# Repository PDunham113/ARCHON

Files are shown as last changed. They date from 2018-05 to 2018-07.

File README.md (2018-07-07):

# ARCHON
**A**ddressable **R**GB LED **CON**troller *(The **'h'** is nonexistent)*

The ultimate goal is to control an arbitrary number of addressable (WS2812 or
similar) from an ATMega328p, with a robust serial protocol to communicate to a
IoT-friendly mainboard (Raspberry Pi Zero W or similar).

Current state is somewhat less than that (setting up tools, etc.)

## Folders

### hardware (v0.0.0)
Contains EAGLE files for the ARCHON controller board

### software (v0.0.0)
Contains firmware for ARCHON

## Setup
Working with the hardware requires an installation of Autodesk EAGLE (v8.5.2 or
later), as well as a copy of Sparkfun's EAGLE library. Installation is left up
to the user.

Working with the software requires a number of (non-Windows-friendly) tools. To
automate the installation process and facilitate the ability to work on
multiple projects at once, a Vagrantfile is maintained with all the required
tools and dependencies.

### Installing Vagrant
You will need:
-   Vagrant [(HashiCorp)][vagrant_install]
-   VirtualBox [(Oracle)][virtualbox_install]
    -   Other VMs are available, but not actively supported by this project
-   VirtualBox Extensions [(Same place)][virtualbox_install]

The Vagrantfile used here is split into 3 parts.
-   `Vagrantfile`
    -   Deals with general configuration of VM instance
-   `Vagrantfile.project`
    -   Deals with project-specific tools and dependencies
-   `Vagrantfile.local`
    -   Deals with user preferences and machine-specific settings. As this is
        user-specific, Git will ignore this. A template
        (`Vagrantfile.local.example`) is included. Rename and enjoy!

To boot the VM, navigate to the project folder and run the following commands:
```
vagrant up
vagrant ssh
```

#### Common Errors
-   Ensure that virtualization extensions are enabled (you may need to check
    your BIOS)

[vagrant_install]: https://www.vagrantup.com/downloads.html
[virtualbox_install]: https://www.virtualbox.org/wiki/Downloads

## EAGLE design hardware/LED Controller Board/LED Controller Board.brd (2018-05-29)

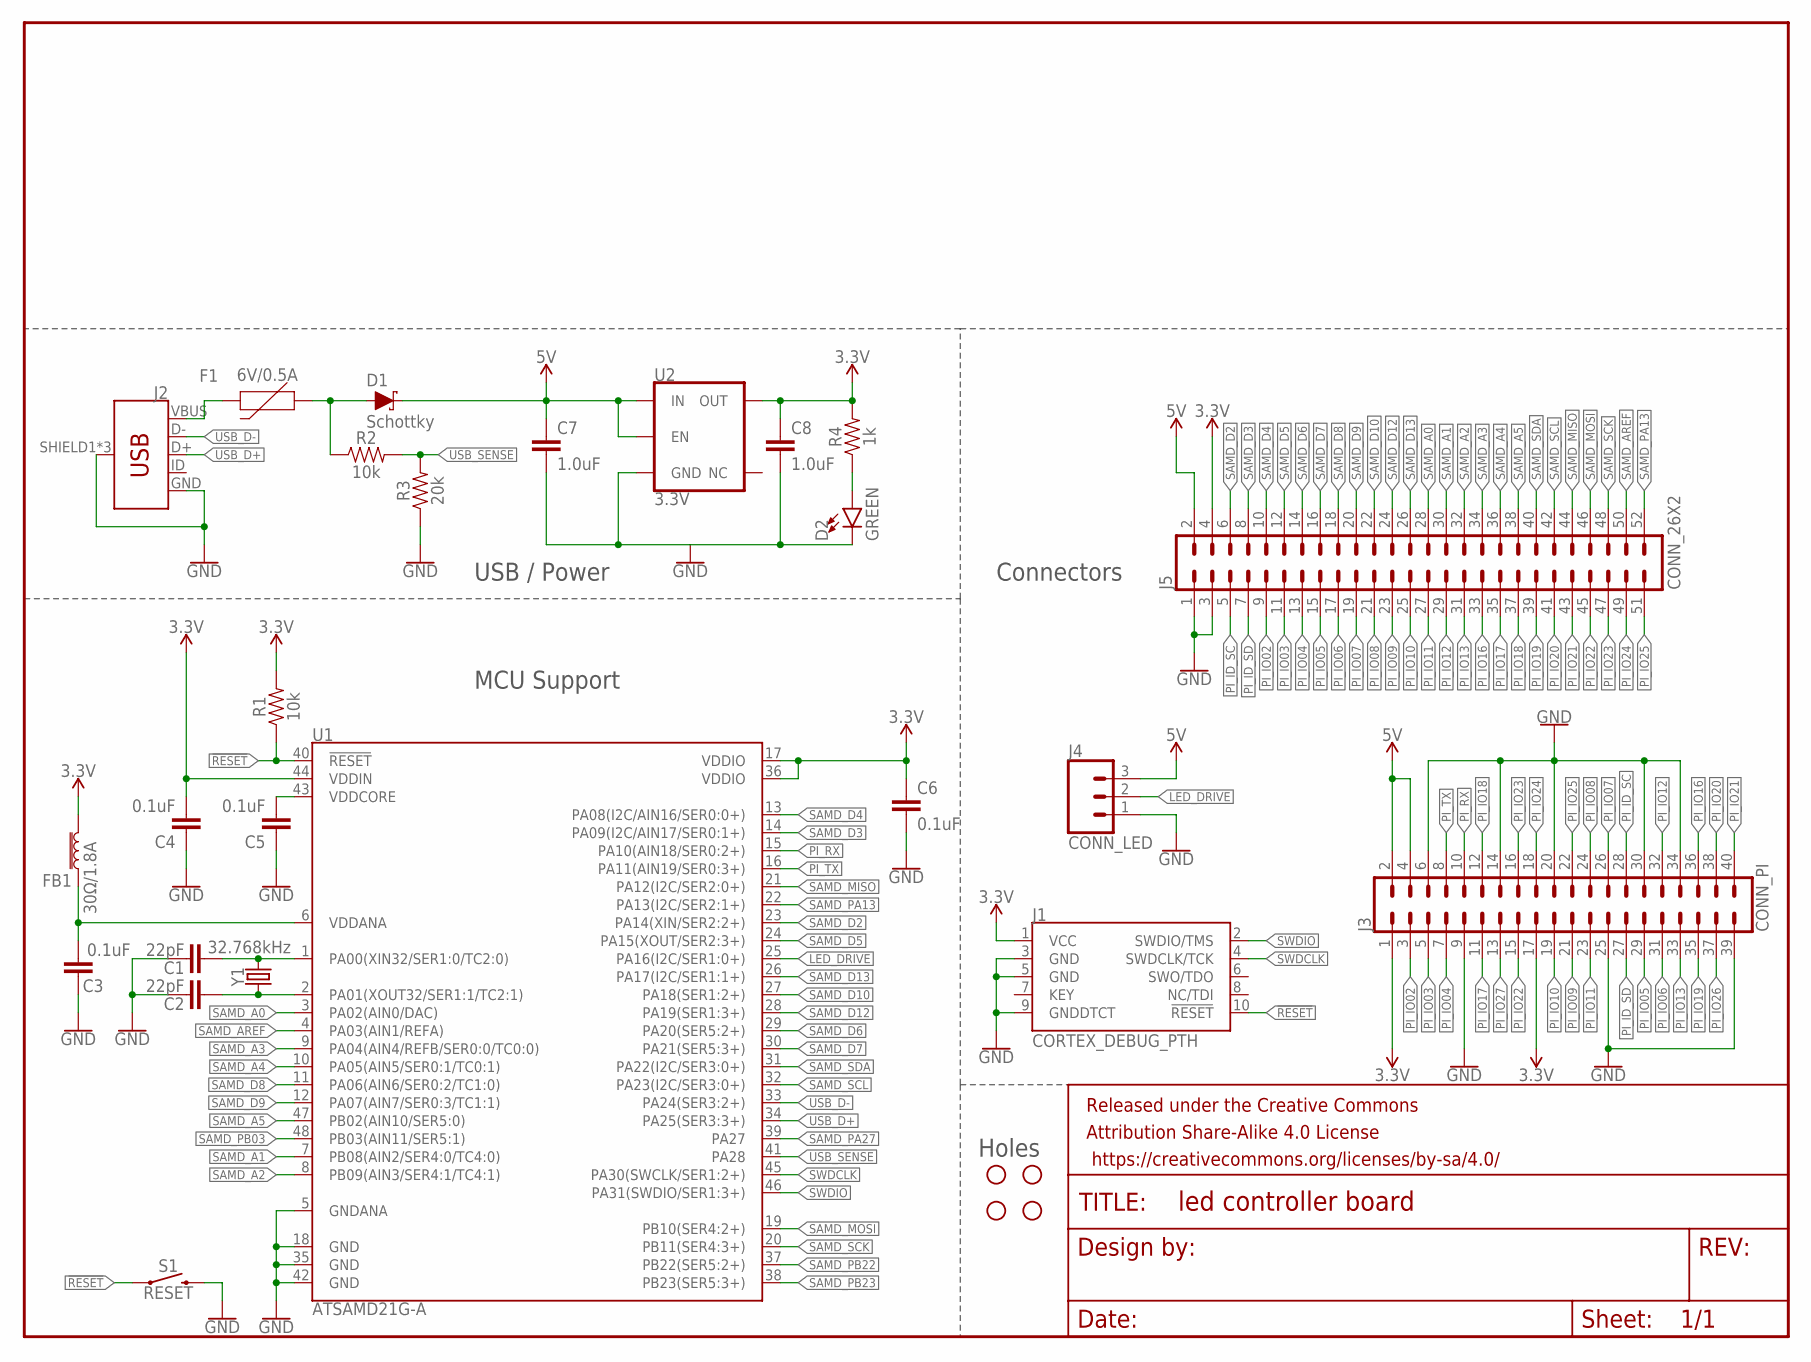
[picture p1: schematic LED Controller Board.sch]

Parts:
C1, C2: 22pF; 0603
C3, C4, C5, C6: 0.1uF; 0603
C7, C8: 1.0uF; 0603
D1: Schottky; SOD-323
D2: GREEN; LED-0603
F1: 6V/0.5A; 1206
FB1: 30Ω/1.8A; 0603
FRAME1: FRAME-LETTERNO_PACKAGE; DUMMY
H1, H2, H3, H4: STAND-OFFTIGHT; STAND-OFF-TIGHT
J1: CORTEX_DEBUG_PTH; 2X5-PTH-1.27MM
J2: USB_MICRO-B_FEMALE-SMT; USB-B-MICRO-SMD
J3: CONN_PI; 2X20
J4: CONN_LED; 1X03_LOCK
J5: CONN_26X2; 2X26
R1, R2: 10k; 0603
R3: 20k; 0603
R4: 1k; 0603
S1: RESET; TACTILE_SWITCH_PTH_RIGHT_ANGLE_KIT
U1: ATSAMD21G-A; TQFP-48
U2: 3.3V; SOT23-5
Y1: 32.768kHz; CRYSTAL-SMD-3.2X1.5MM

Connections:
3.3V: C4.2, C6.1, C8.1, FB1.2, J1.1 (VCC), J3.1, J3.17, J5.4, R1.2, R4.2, U1.17 (VDDIO), U1.36 (VDDIO), U1.44 (VDDIN), U2.5 (OUT)
5V: C7.1, D1.C, J3.2, J3.4, J4.3, J5.2, U2.1 (IN), U2.3 (EN)
!RESET: J1.10 (!RESET), R1.1, S1.1, U1.40 (!RESET!)
GND: C1.1, C2.1, C3.1, C4.1, C5.1, C6.2, C7.2, C8.2, D2.C, J1.3 (GND), J1.5 (GND), J1.9 (GNDDTCT), J2.GND, J2.SHIELD1 (SHIELD), J2.SHIELD2 (SHIELD), J2.SHIELD3 (SHIELD), J3.6, J3.9, J3.14, J3.20, J3.25, J3.30, J3.34, J3.39, J4.1, J5.1, J5.3, R3.1, S1.2, U1.5 (GNDANA), U1.18 (GND), U1.35 (GND), U1.42 (GND), U2.2 (GND)
LED_DRIVE: J4.2, U1.25 (PA16(I2C/SER1:0+))
unnamed: C1.2, U1.1 (PA00(XIN32/SER1:0/TC2:0)), Y1.P$2 (2)
unnamed: C2.2, U1.2 (PA01(XOUT32/SER1:1/TC2:1)), Y1.P$1 (1)
unnamed: C3.2, FB1.1, U1.6 (VDDANA)
unnamed: C5.2, U1.43 (VDDCORE)
unnamed: F1.2, J2.VBUS
unnamed: D1.A, F1.1, R2.1
unnamed: D2.A, R4.1
PI_ID_SC: J3.28, J5.5
PI_ID_SD: J3.27, J5.7
PI_IO02: J3.3, J5.9
PI_IO03: J3.5, J5.11
PI_IO04: J3.7, J5.13
PI_IO05: J3.29, J5.15
PI_IO06: J3.31, J5.17
PI_IO07: J3.26, J5.19
PI_IO08: J3.24, J5.21
PI_IO09: J3.21, J5.23
PI_IO10: J3.19, J5.25
PI_IO11: J3.23, J5.27
PI_IO12: J3.32, J5.29
PI_IO13: J3.33, J5.31
PI_IO16: J3.36, J5.33
PI_IO17: J3.11, J5.35
PI_IO18: J3.12, J5.37
PI_IO19: J3.35, J5.39
PI_IO20: J3.38, J5.41
PI_IO21: J3.40, J5.43
PI_IO22: J3.15, J5.45
PI_IO23: J3.16, J5.47
PI_IO24: J3.18, J5.49
PI_IO25: J3.22, J5.51
PI_IO26: J3.37
PI_IO27: J3.13
PI_RX: J3.10, U1.15 (PA10(AIN18/SER0:2+))
PI_TX: J3.8, U1.16 (PA11(AIN19/SER0:3+))
SAMD_A0: J5.28, U1.3 (PA02(AIN0/DAC))
SAMD_A1: J5.30, U1.7 (PB08(AIN2/SER4:0/TC4:0))
SAMD_A2: J5.32, U1.8 (PB09(AIN3/SER4:1/TC4:1))
SAMD_A3: J5.34, U1.9 (PA04(AIN4/REFB/SER0:0/TC0:0))
SAMD_A4: J5.36, U1.10 (PA05(AIN5/SER0:1/TC0:1))
SAMD_A5: J5.38, U1.47 (PB02(AIN10/SER5:0))
SAMD_AREF: J5.50, U1.4 (PA03(AIN1/REFA))
SAMD_D2: J5.6, U1.23 (PA14(XIN/SER2:2+))
SAMD_D3: J5.8, U1.14 (PA09(I2C/AIN17/SER0:1+))
SAMD_D4: J5.10, U1.13 (PA08(I2C/AIN16/SER0:0+))
SAMD_D5: J5.12, U1.24 (PA15(XOUT/SER2:3+))
SAMD_D6: J5.14, U1.29 (PA20(SER5:2+))
SAMD_D7: J5.16, U1.30 (PA21(SER5:3+))
SAMD_D8: J5.18, U1.11 (PA06(AIN6/SER0:2/TC1:0))
SAMD_D9: J5.20, U1.12 (PA07(AIN7/SER0:3/TC1:1))
SAMD_D10: J5.22, U1.27 (PA18(SER1:2+))
SAMD_D12: J5.24, U1.28 (PA19(SER1:3+))
SAMD_D13: J5.26, U1.26 (PA17(I2C/SER1:1+))
SAMD_MISO: J5.44, U1.21 (PA12(I2C/SER2:0+))
SAMD_MOSI: J5.46, U1.19 (PB10(SER4:2+))
SAMD_PA13: J5.52, U1.22 (PA13(I2C/SER2:1+))
SAMD_PA27: U1.39 (PA27)
SAMD_PB03: U1.48 (PB03(AIN11/SER5:1))
SAMD_PB22: U1.37 (PB22(SER5:2+))
SAMD_PB23: U1.38 (PB23(SER5:3+))
SAMD_SCK: J5.48, U1.20 (PB11(SER4:3+))
SAMD_SCL: J5.42, U1.32 (PA23(I2C/SER3:0+))
SAMD_SDA: J5.40, U1.31 (PA22(I2C/SER3:0+))
SWDCLK: J1.4 (SWDCLK/TCK), U1.45 (PA30(SWCLK/SER1:2+))
SWDIO: J1.2 (SWDIO/TMS), U1.46 (PA31(SWDIO/SER1:3+))
USB_D+: J2.D+, U1.34 (PA25(SER3:3+))
USB_D-: J2.D-, U1.33 (PA24(SER3:2+))
USB_SENSE: R2.2, R3.2, U1.41 (PA28)

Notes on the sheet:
MCU Support
Connectors
USB / Power
Holes

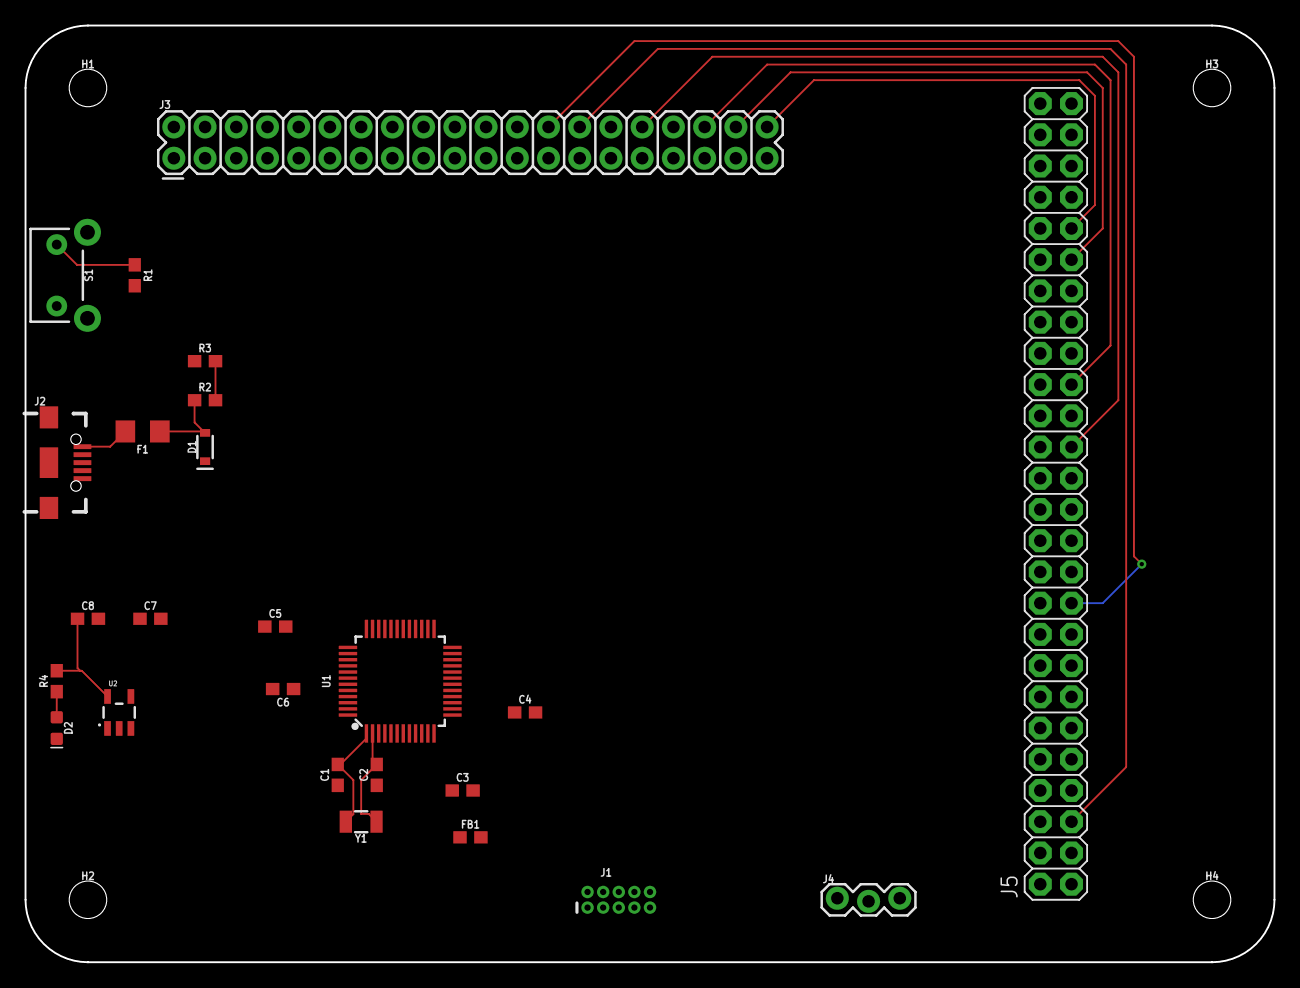
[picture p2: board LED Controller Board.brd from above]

Board: 2 copper layers, 101.6 x 76.2 mm, 30 parts (0 on the bottom side), 67 nets.

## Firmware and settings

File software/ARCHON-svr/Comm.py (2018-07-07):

"""Python-side communication with COMM.c.

Commands:
    COM_PKT_EMPTY <0x00>
        Completely empty packet, 0 length, no data. Use for heartbeats, etc.
    COM_PKT_TEST <0x01>
        No restrictions on contents, use for testing only. Each packet may
        contain an arbitrary number of LED data entries.
    COM_PKT_BUSY
        Indicates the device sending is busy - data is ignored. Packets sent to
        the device are not guaranteed to be processed until device sends a
        COM_PKT_READY.
    COM_PKT_LED_CTRL
        Execute one of various LED commands, specified by the first data byte.
        Supported commands are:

        CHANGE_BLOCK <0x42>
            Change which 8-bit block the LED_DATA packet writes to. Second byte
            specifies the new block to write to.
        COPY <0x43>
            Copy the value of one LED to multiple other LEDs. Second byte
            specifies the parent LED, all other bytes specify child LEDs.
        ERASE <0x45>
            Sets all LEDs within the block to 0. No additional parameters.
        PUSH <0x50>
            Force an immediate update of the RGB LEDs with whatever is in the
            buffers. No additional parameters.
    COM_PKT_LED_DATA
        Update with new RGB LED data, each LED is expressed in 4 bytes. The
        format is:
        ```
        <LED_NUM><R_VAL><G_VAL><B_VAL>
        ```
    COM_PKT_READY
        Indicates the device sending is ready to recieve - data is ignored.
        Packets sent to the device are guaranteed to be processed until
        device sends a COM_PKT_BUSY.

NOTE: The byte values of com_type are currently left undefined, except for
      COM_PKT_EMPTY and COM_PKT_TEST.
"""
import argparse
from collections import namedtuple

import serial

DEFAULT_PORT = "/dev/ttyUSB0/"
DEFAULT_BAUD = 9600

START_CHAR = b"\x15"

CommMessage = namedtuple("CommMessage", [
    "type",  # type: bytearray
    "length",  # type: bytearray
    "data",  # type: bytearray
    "checksum",  # type: bytearray
])


def calc_checksum(msg: CommMessage) -> CommMessage:
    """Calculate message checksum from individual components.

    Currently XORS all of the things together. Checksum is calculated in-place.
    It is expected that the checksum bytearray has one element initialized to
    0.

    @param CommMessage Message to calculate checksum for.

    @returns CommMessage tuple with calculated checksum.

    @raises None.
    """
    checksum = msg.length[0] ^ msg.type[0]

    for byte in msg.data:
        checksum ^= byte

    msg.checksum[0] = checksum

    return msg


def calc_message(type: bytearray, data: bytearray) -> CommMessage:
    """Calculate length & checksum of message given data & type.

    @param type Number representing type of message.
    @param data Iterable containing message data.

    @returns CommMessage tuple containing calculated message.

    @raises None.
    """
    message = CommMessage(type, bytearray([len(data)]), data, bytearray(1))
    calc_checksum(message)

    return message


def send_message(port: serial.Serial, msg: CommMessage):
    """Send the calculated message over serial.

    Sends bytes in the following order:
    -   SOM character
    -   Message type
    -   Message length
    -   Message data
    -   Message checksum

    Will only send up to msg.length bytes - no more, no less.

    @param port The serial port to send the message over - it is assumed to be
                open.
    @param msg CommMessage tuple containing calculated message.

    @returns None.

    @raises None.
    """
    port.write(START_CHAR)
    port.write(msg.type)
    port.write(msg.length)
    port.write(msg.data[:msg.length])
    port.write(msg.checksum)


def print_message(msg: CommMessage):
    """Print CommMessage in terminal.

    Prints hexadecimal representation of each byte in message, in addition to
    the field to which each byte belongs.

    @param msg CommMessage tuple containing message to print.

    @returns None.

    @raises None.
    """
    text_msg = [
        "SOM:\t0x15\n",
        "TYPE:\t0x{}\n".format(msg.type.hex()),
        "LENGTH:\t0x{}\n".format(msg.length.hex()),
        "DATA:\t{}\n".format(":".join(
            ["0x{}".format(msg.data.hex()[i:i + 2])
             for i in range(0, len(msg.data.hex()), 2)])),
        "CHKSM:\t0x{}\n".format(msg.checksum.hex()),
    ]

    print("".join(text_msg))


if __name__ == "__main__":
    """Interface for testing and sending messages to RGB hardware."""
    parser = argparse.ArgumentParser(description="RGB Communication Terminal")

    parser.add_argument("command_type", type=int)

    parser.add_argument("command_data", type=int, nargs="+")

    args = parser.parse_args()

    # Convert to bytearray
    args.command_type = bytearray([args.command_type])
    args.command_data = bytearray(args.command_data)

    msg = calc_message(args.command_type, args.command_data)

    print_message(msg)

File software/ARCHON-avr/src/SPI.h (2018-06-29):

/** @file SPI.h
 *  @brief Driver for ATMEGA328P SPI
 *
 *  Minimal SPI driver for the above. Not compatible with `fprintf()`. Places
 *  device in master mode.
 *
 *  TODO: Add support for changing SPI settings at start of transaction.
 *  TODO: Add support for multiple SS pins.
 *  TODO: Add support for multiple SPI ports.
 *
 *  @author Patrick Dunham
 *  @bug No known bugs.
 *  @version 0.0.1
 */

#ifndef SPI_H
#define SPI_H

#include <avr/io.h>
#include <stdint.h>


/* -- VARIABLES & DEFINITIONS -- */

// SPI Port Definitions
#define SPI_DDR  DDRB
#define SPI_PORT PORTB
#define SPI_PIN  PINB

// SPI Pin Definitions
#define SPI_MOSI PINB3
#define SPI_MISO PINB4
#define SPI_SCK  PINB5
#define SPI_SS   PINB2

// SPI Bit Order
#define SPI_MSB_FIRST 0
#define SPI_LSB_FIRST 1

// SPI Bus Mode
#define SPI_MASTER    0
#define SPI_SLAVE     1

// SPI Clock Mode
#define SPI_MODE_0    0
#define SPI_MODE_1    1
#define SPI_MODE_2    2
#define SPI_MODE_3    3

// SPI Clock Dividers
#define SPI_DIV_2     0
#define SPI_DIV_4     1
#define SPI_DIV_8     2
#define SPI_DIV_16    3
#define SPI_DIV_32    4
#define SPI_DIV_64    5
#define SPI_DIV_64_2X 6 // /128 with SPI2X enabled - should equal SPI_DIV_64
#define SPI_DIV_128   7

// SPI Interrupts
#define SPI_INT       0
#define SPI_NO_INT    1

typedef struct spi_settings_ {
  uint8_t bus_mode  : 1;
  uint8_t bit_order : 1;
  uint8_t interrupt : 1;
  uint8_t clk_mode  : 2;
  uint8_t speed     : 3;
} spi_settings_t;

// Private
static spi_settings_t spi_default_settings;

/* -- PUBLIC FUNCTIONS -- */

/** @brief Start SPI transmission
 *
 *  Pulls SS pin low using default SPI settings. Call to start sending a series
 *  of bytes over SPI. Currently uses the chip default SS pin.
 */
 inline void spi_begin_transmission(void) {
   SPI_PORT &= ~(1 << SPI_SS);
 }

/** @brief End SPI transmission
 *
 *  Pulls SS pin high using default SPI settings. Call to end sending a series
 *  of bytes over SPI. Currently uses the chip default SS pin.
 */
 inline void spi_end_transmission(void) {
   SPI_PORT |= (1 << SPI_SS);
 }

/** @brief Initialize SPI bus to specified parameters
 *
 *  These settings will be used if none are specified in
 *  `spi_begin_transmission`. Master mode will set MOSI, SCK, and SS as
 *  outputs, and MISO as an input, as well as pull SS high. Slave mode will set
 *  MOSI, SCK, SS as inputs, and MISO as an output. It is assumed that SS is
 *  the default specified by the device - only one SS is currently supported.
 *
 *  NOTE: Any previous SPI configuration will be overwritten.
 *
 *  @param _default_settings The settings to initialize the SPI bus to.
 *  @returns Void.
 */
void spi_init(spi_settings_t _default_settings);

/** @brief Recieves a character from the SPI buffer.
 *
 *  Will return immediatly with the buffer contents.
 *
 *  @returns The raw byte received over SPI
 */
inline uint8_t spi_recv(void) {
  return SPDR;
}

/** @brief Recieves a character from the SPI buffer, blocking for valid data.
 *
 *  Will return when a character has been received over SPI
 *
 *  @returns The raw byte received over SPI
 */
uint8_t spi_recv_block(void);

/** @brief Recieves a character from the SPI buffer, blocking w/ timeout.
 *
 *  Will return when a character has been received over SPI, or when the
 *  timeout expires. The timeout is expressed as the number of loop iterations
 *  in the function below. Experimentation is needed to determine a real-world
 *  time equivalent.
 *
 *  @param _timeout Max time to wait for new character, in arbitrary units
 *  @returns The raw byte received over SPI
 */
uint8_t spi_recv_timeout(uint32_t _timeout);

/** @brief Queues a single character to be sent over SPI.
 *
 *  Will return immediatly.
 *
 *  @param _data The raw byte to send over SPI
 *  @returns Void.
 */
 inline void spi_send(uint8_t _data) {
   SPDR = _data;
 }

/** @brief Sends a character over SPI, blocking until it is sent.
 *
 *  Will return when the character is sent
 *
 *  @param _data The raw byte to send over SPI
 *  @returns Void.
 */
void spi_send_block(uint8_t _data);


#endif /* SPI_H */

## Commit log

2018-05-29 Add initial hardware layout
    [LED Controller Board.brd, LED Controller Board.sch]
2018-06-15 Seperate into hardware/software, add comm library
    [LED Controller Board.brd, LED Controller Board.sch]
2018-06-15 Restructure .gitignore
    Top-level & major subfolders each have their own file. Top-level
    currently ignores Vagrant crap; hardware ignored Eagle crap; software
    ignores software crap.
2018-06-15 Add initialization code, millis timer
2018-06-17 Fix comm config section
    Allow selection of "interrupt" function w/o delving into .c
2018-06-24 Create SPI module
2018-06-26 Create interface for RGB LEDs
2018-06-29 Move millis timer to module.
2018-06-29 Create RGB LED message protocol

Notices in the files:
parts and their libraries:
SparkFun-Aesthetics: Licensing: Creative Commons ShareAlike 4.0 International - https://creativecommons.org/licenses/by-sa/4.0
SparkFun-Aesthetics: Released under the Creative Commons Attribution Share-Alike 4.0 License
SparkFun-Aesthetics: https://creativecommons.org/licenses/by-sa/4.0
